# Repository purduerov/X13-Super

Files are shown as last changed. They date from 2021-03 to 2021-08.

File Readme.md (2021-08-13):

# X13-Super-Module

This is an advanced way to manage all the board repos for IEEE ROV. 
Each board's repo is treated as a submodule. 
Git submodules do not track the files inside a submodule, they only point to a commit in the submodule.

### Updating to changes

To get the version pointed at by the super module (this repo), run:  
`git submodule update --init --recursive`  
This can be accessed easier via:  
`git config --global alias.sup 'submodule update --init --recursive'`  
so that you can then type `git sup`

When you cd into a submodule, you will be in a detached HEAD state. You will want to
`git switch` or `git checkout` a branch. To find the branches, run `git branch` or
`git branch -r` to see remote branches.

To get the latest version of each submodule, run:  
`git submodule foreach --recursive git pull`.  
Note: you must be on a branch in order to do this.
Alternatively, running `git submodule update --remote` will pull the latest
commits from the branch tracked in `.gitmodules`, but will finished in a detached head state.

To set up a new submodule, run:  
`git submodule add link.copied.from.github`  
To add tracking the for a branch such as master, use:  
`git submodule add -b master link.copied.from.github`  

### Other: Merging and merge conflicts
Running `git merge --ff-only` or `git pull --ff--only` will prevent git from automatically trying to merge
diverged histories. If you are in a conflict merge commit and want to exit, run `git merge --quit`.  

To merge two branches that have diverged, you have several options. 
1. `git merge -s recursive -X ours` and `git merge -s recursive -X theirs` will attempt to interleave
changes from both files. When conflicts arise, it will prefer local/current (ours) changes in 
`-X ours` and the remote/merging branch (theirs) changes in `-X theirs`.
2. `git merge -s ours` this will "merge" the other branch, but discard all of it's changes.
3. If you have diverged histories and want to delete yours, you can "undo" or "delete" several commits,
then fast-forward merge. It is recommended to first make a "backup" branch (rather than messing with reflog), 
by running `git branch local-backup` (local-backup can be any name). Then run `git reset --hard HEAD~N` where
`N` is the number of commits to undo. The run `git merge branch-name` or `git pull` to fastforward merge the
other branch.

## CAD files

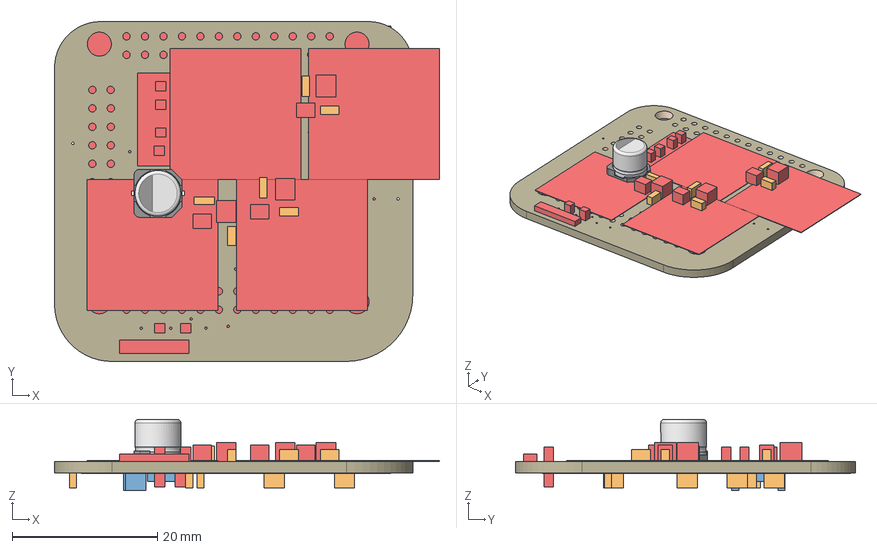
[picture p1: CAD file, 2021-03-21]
NeoCoreShield2.step
52.9 x 46.7 x 9.83 mm
Board
BINDER_M12_PAR_8_DIP x 4
ETH-TRANS
10k x 11
1.0nF
0.1uF x 2
JUMPER-SMT_2_NO_SILK x 8
RED x 6
2.5A/30V/105mΩ x 3
NANO_PI_NEO_CORE
1X04
310mA/60V/1.6Ω x 3
WSIZE CODE D-001
WSIZE CODE D-002
WSIZE CODE D-003 x 2

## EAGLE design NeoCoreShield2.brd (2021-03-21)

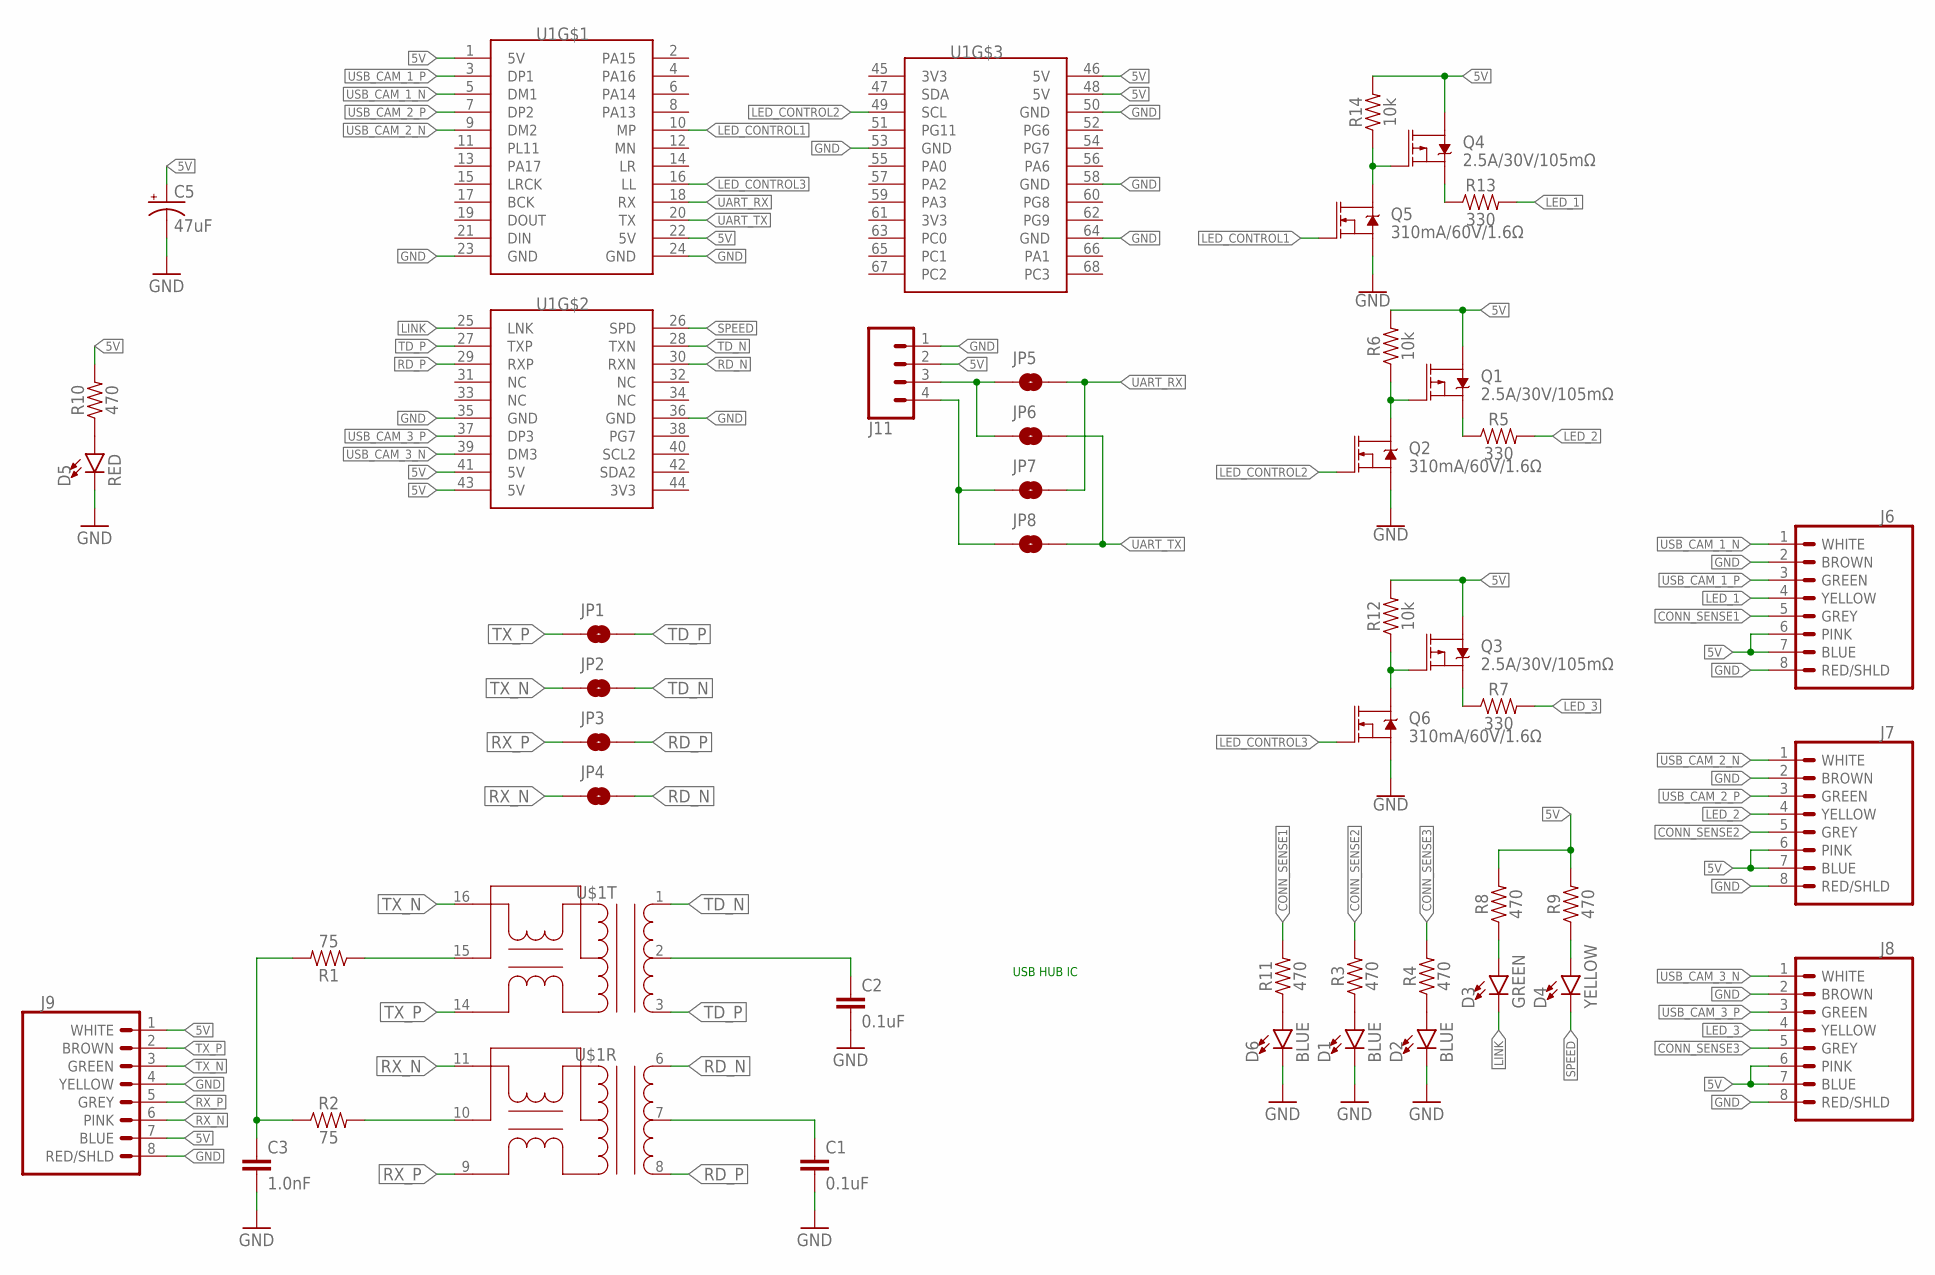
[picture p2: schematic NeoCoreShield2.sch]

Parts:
C1, C2: 0.1uF; 0603
C3: 1.0nF; 1206
C5: 47uF; PANASONIC_D
D1, D2, D6: BLUE; 0805
D3: GREEN; 0805
D4: YELLOW; 0805
D5: RED; 0805
J6, J7, J8, J9: BINDER_M12_PAR_8_DIP
J11: CONN_04; 1X04
JP1, JP2, JP3, JP4, JP5, JP6, JP7, JP8: JUMPER-SMT_2_NO_SILK; SMT-JUMPER_2_NO_SILK
Q1, Q3, Q4: 2.5A/30V/105mΩ; SOT23-3
Q2, Q5, Q6: 310mA/60V/1.6Ω; SOT323
R1, R2: 75; 0603
R3, R4, R8, R9, R10, R11: 470; 0603
R5, R7, R13: 330; 0805
R6, R12, R14: 10k; 0603
U1: NANO_PI_NEO_CORE
U$1: ETH-TRANS; SOIC-16-WIDE

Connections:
5V: C5.+, J6.6 (PINK), J6.7 (BLUE), J7.6 (PINK), J7.7 (BLUE), J8.6 (PINK), J8.7 (BLUE), J9.1 (WHITE), J9.7 (BLUE), J11.2, Q1.3 (D), Q3.3 (D), Q4.3 (D), R6.2, R8.2, R9.2, R10.2, R12.2, R14.2, U1.1 (5V), U1.22 (5V), U1.41 (5V), U1.43 (5V), U1.46 (5V), U1.48 (5V)
CONN_SENSE1: J6.5 (GREY), R11.2
CONN_SENSE2: J7.5 (GREY), R3.2
CONN_SENSE3: J8.5 (GREY), R4.2
ETH_TD0_GND: C1.1, U$1.7 (CT)
ETH_TD1_GND: C2.1, U$1.2 (CT)
ETH_TERM_MID: C3.1, R1.2, R2.1
GND: C1.2, C2.2, C3.2, C5.-, D1.C, D2.C, D5.C, D6.C, J6.2 (BROWN), J6.8 (RED/SHLD), J7.2 (BROWN), J7.8 (RED/SHLD), J8.2 (BROWN), J8.8 (RED/SHLD), J9.4 (YELLOW), J9.8 (RED/SHLD), J11.1, Q2.2 (S), Q5.2 (S), Q6.2 (S), U1.23 (GND), U1.24 (GND), U1.35 (GND), U1.36 (GND), U1.50 (GND), U1.53 (GND), U1.58 (GND), U1.64 (GND)
LED_1: J6.4 (YELLOW), R13.2
LED_2: J7.4 (YELLOW), R5.2
LED_3: J8.4 (YELLOW), R7.2
LED_CONTROL1: Q5.1 (G), U1.10 (MP)
LED_CONTROL2: Q2.1 (G), U1.49 (SCL)
LED_CONTROL3: Q6.1 (G), U1.16 (LL)
LINK: D3.C, U1.25 (LNK)
LINK_MID: D3.A, R8.1
unnamed: D1.A, R3.1
unnamed: D2.A, R4.1
unnamed: R2.2, U$1.10 (XCT)
unnamed: D6.A, R11.1
unnamed: Q3.2 (S), R7.1
unnamed: Q3.1 (G), Q6.3 (D), R12.1
unnamed: D5.A, R10.1
unnamed: Q1.2 (S), R5.1
unnamed: Q1.1 (G), Q2.3 (D), R6.1
unnamed: Q4.2 (S), R13.1
unnamed: R1.1, U$1.15 (XCT)
unnamed: Q4.1 (G), Q5.3 (D), R14.1
RD_N: JP4.2, U1.30 (RXN), U$1.6 (D+)
RD_P: JP3.2, U1.29 (RXP), U$1.8 (D-)
RX_N: J9.6 (PINK), JP4.1, U$1.11 (X+)
RX_P: J9.5 (GREY), JP3.1, U$1.9 (X-)
SPEED: D4.C, U1.26 (SPD)
SPEED_MID: D4.A, R9.1
TD_N: JP2.2, U1.28 (TXN), U$1.1 (D+)
TD_P: JP1.2, U1.27 (TXP), U$1.3 (D-)
TX_N: J9.3 (GREEN), JP2.1, U$1.16 (X+)
TX_P: J9.2 (BROWN), JP1.1, U$1.14 (X-)
UART_RX: JP5.2, JP7.2, U1.18 (RX)
UART_RX_TX: J11.3, JP5.1, JP6.1
UART_TX: JP6.2, JP8.2, U1.20 (TX)
UART_TX_RX: J11.4, JP7.1, JP8.1
USB_CAM_1_N: J6.1 (WHITE), U1.5 (DM1)
USB_CAM_1_P: J6.3 (GREEN), U1.3 (DP1)
USB_CAM_2_N: J7.1 (WHITE), U1.9 (DM2)
USB_CAM_2_P: J7.3 (GREEN), U1.7 (DP2)
USB_CAM_3_N: J8.1 (WHITE), U1.39 (DM3)
USB_CAM_3_P: J8.3 (GREEN), U1.37 (DP3)

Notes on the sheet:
USB HUB IC

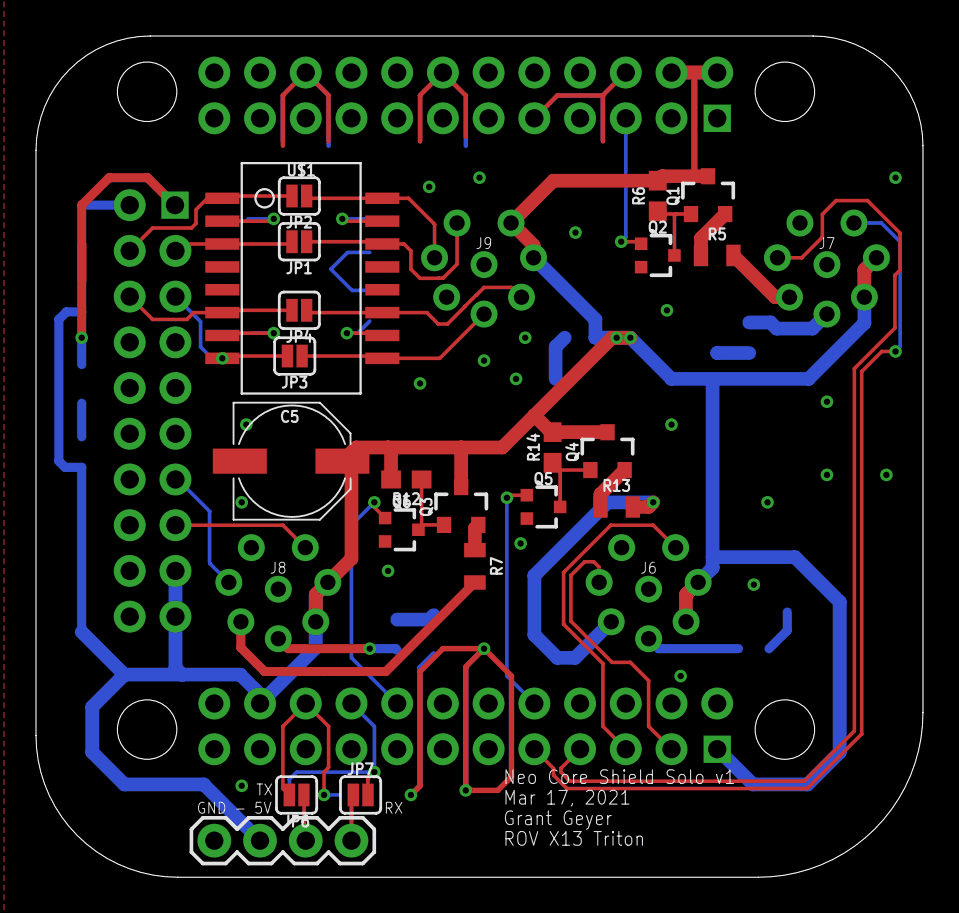
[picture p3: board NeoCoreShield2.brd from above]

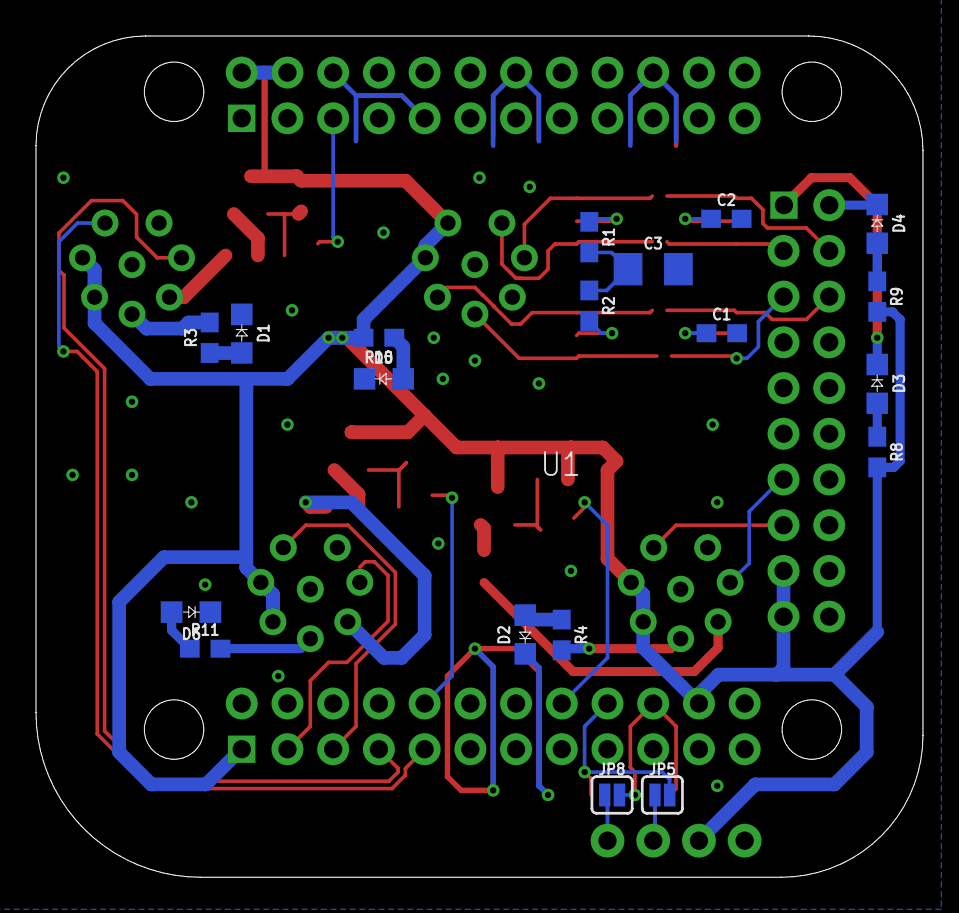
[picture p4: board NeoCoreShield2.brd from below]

Board: 2 copper layers, 49.3 x 46.7 mm, 45 parts (20 on the bottom side), 48 nets.

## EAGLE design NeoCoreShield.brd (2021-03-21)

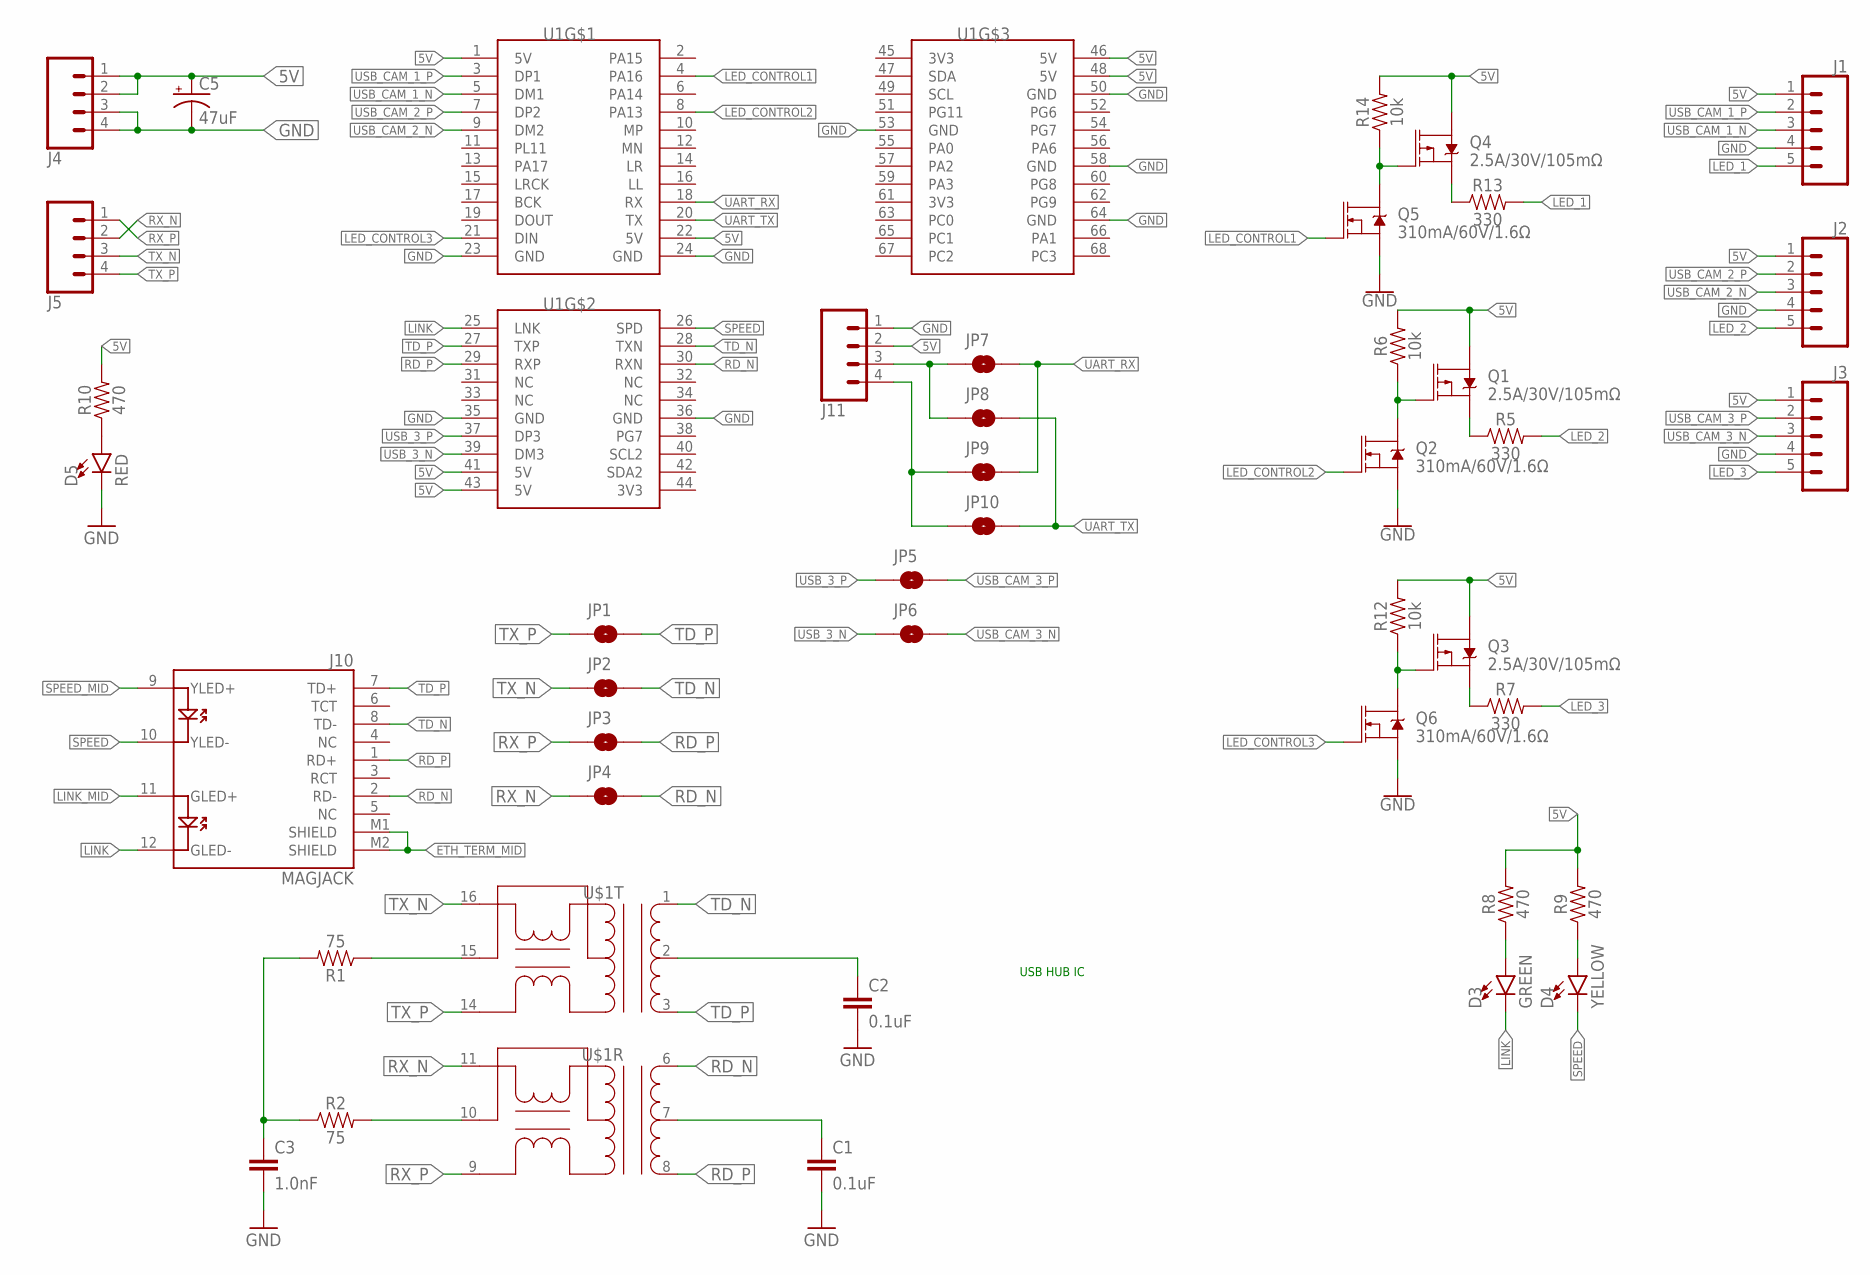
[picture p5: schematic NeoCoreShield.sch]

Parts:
C1, C2: 0.1uF; 0603
C3: 1.0nF; 1206
C5: 47uF; PANASONIC_D
D3: GREEN; 0805
D4: YELLOW; 0805
D5: RED; 0805
J1, J2, J3: PXC-PTSM-05-RA
J4, J5: PXC-PTSM-04-RA-1778641
J10: MAGJACK
J11: CONN_04; 1X04
JP1, JP2, JP3, JP4, JP5, JP6, JP7, JP8, JP9, JP10: JUMPER-SMT_2_NO_SILK; SMT-JUMPER_2_NO_SILK
Q1, Q3, Q4: 2.5A/30V/105mΩ; SOT23-3
Q2, Q5, Q6: 310mA/60V/1.6Ω; SOT323
R1, R2: 75; 0603
R5, R7, R13: 330; 0805
R6, R12, R14: 10k; 0603
R8, R9, R10: 470; 0603
U1: NANO_PI_NEO_CORE
U$1: ETH-TRANS; SOIC-16-WIDE

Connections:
5V: C5.+, J1.1, J2.1, J3.1, J4.1, J4.2, J11.2, Q1.3 (D), Q3.3 (D), Q4.3 (D), R6.2, R8.2, R9.2, R10.2, R12.2, R14.2, U1.1 (5V), U1.22 (5V), U1.41 (5V), U1.43 (5V), U1.46 (5V), U1.48 (5V)
ETH_TD0_GND: C1.1, U$1.7 (CT)
ETH_TD1_GND: C2.1, U$1.2 (CT)
ETH_TERM_MID: C3.1, J10.M1 (SHIELD), J10.M2 (SHIELD), R1.2, R2.1
GND: C1.2, C2.2, C3.2, C5.-, D5.C, J1.4, J2.4, J3.4, J4.3, J4.4, J11.1, Q2.2 (S), Q5.2 (S), Q6.2 (S), U1.23 (GND), U1.24 (GND), U1.35 (GND), U1.36 (GND), U1.50 (GND), U1.53 (GND), U1.58 (GND), U1.64 (GND)
LED_1: J1.5, R13.2
LED_2: J2.5, R5.2
LED_3: J3.5, R7.2
LED_CONTROL1: Q5.1 (G), U1.4 (PA16)
LED_CONTROL2: Q2.1 (G), U1.8 (PA13)
LED_CONTROL3: Q6.1 (G), U1.21 (DIN)
LINK: D3.C, J10.12 (GLED-), U1.25 (LNK)
LINK_MID: D3.A, J10.11 (GLED+), R8.1
unnamed: R2.2, U$1.10 (XCT)
unnamed: Q3.2 (S), R7.1
unnamed: Q3.1 (G), Q6.3 (D), R12.1
unnamed: D5.A, R10.1
unnamed: Q1.2 (S), R5.1
unnamed: Q1.1 (G), Q2.3 (D), R6.1
unnamed: Q4.2 (S), R13.1
unnamed: R1.1, U$1.15 (XCT)
unnamed: Q4.1 (G), Q5.3 (D), R14.1
RD_N: J10.2 (RD-), JP4.2, U1.30 (RXN), U$1.6 (D+)
RD_P: J10.1 (RD+), JP3.2, U1.29 (RXP), U$1.8 (D-)
RX_N: J5.2, JP4.1, U$1.11 (X+)
RX_P: J5.1, JP3.1, U$1.9 (X-)
SPEED: D4.C, J10.10 (YLED-), U1.26 (SPD)
SPEED_MID: D4.A, J10.9 (YLED+), R9.1
TD_N: J10.8 (TD-), JP2.2, U1.28 (TXN), U$1.1 (D+)
TD_P: J10.7 (TD+), JP1.2, U1.27 (TXP), U$1.3 (D-)
TX_N: J5.3, JP2.1, U$1.16 (X+)
TX_P: J5.4, JP1.1, U$1.14 (X-)
UART_RX: JP7.2, JP9.2, U1.18 (RX)
UART_RX_TX: J11.3, JP7.1, JP8.1
UART_TX: JP8.2, JP10.2, U1.20 (TX)
UART_TX_RX: J11.4, JP9.1, JP10.1
USB_3_N: JP6.1, U1.39 (DM3)
USB_3_P: JP5.1, U1.37 (DP3)
USB_CAM_1_N: J1.3, U1.5 (DM1)
USB_CAM_1_P: J1.2, U1.3 (DP1)
USB_CAM_2_N: J2.3, U1.9 (DM2)
USB_CAM_2_P: J2.2, U1.7 (DP2)
USB_CAM_3_N: J3.3, JP6.2
USB_CAM_3_P: J3.2, JP5.2

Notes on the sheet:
USB HUB IC

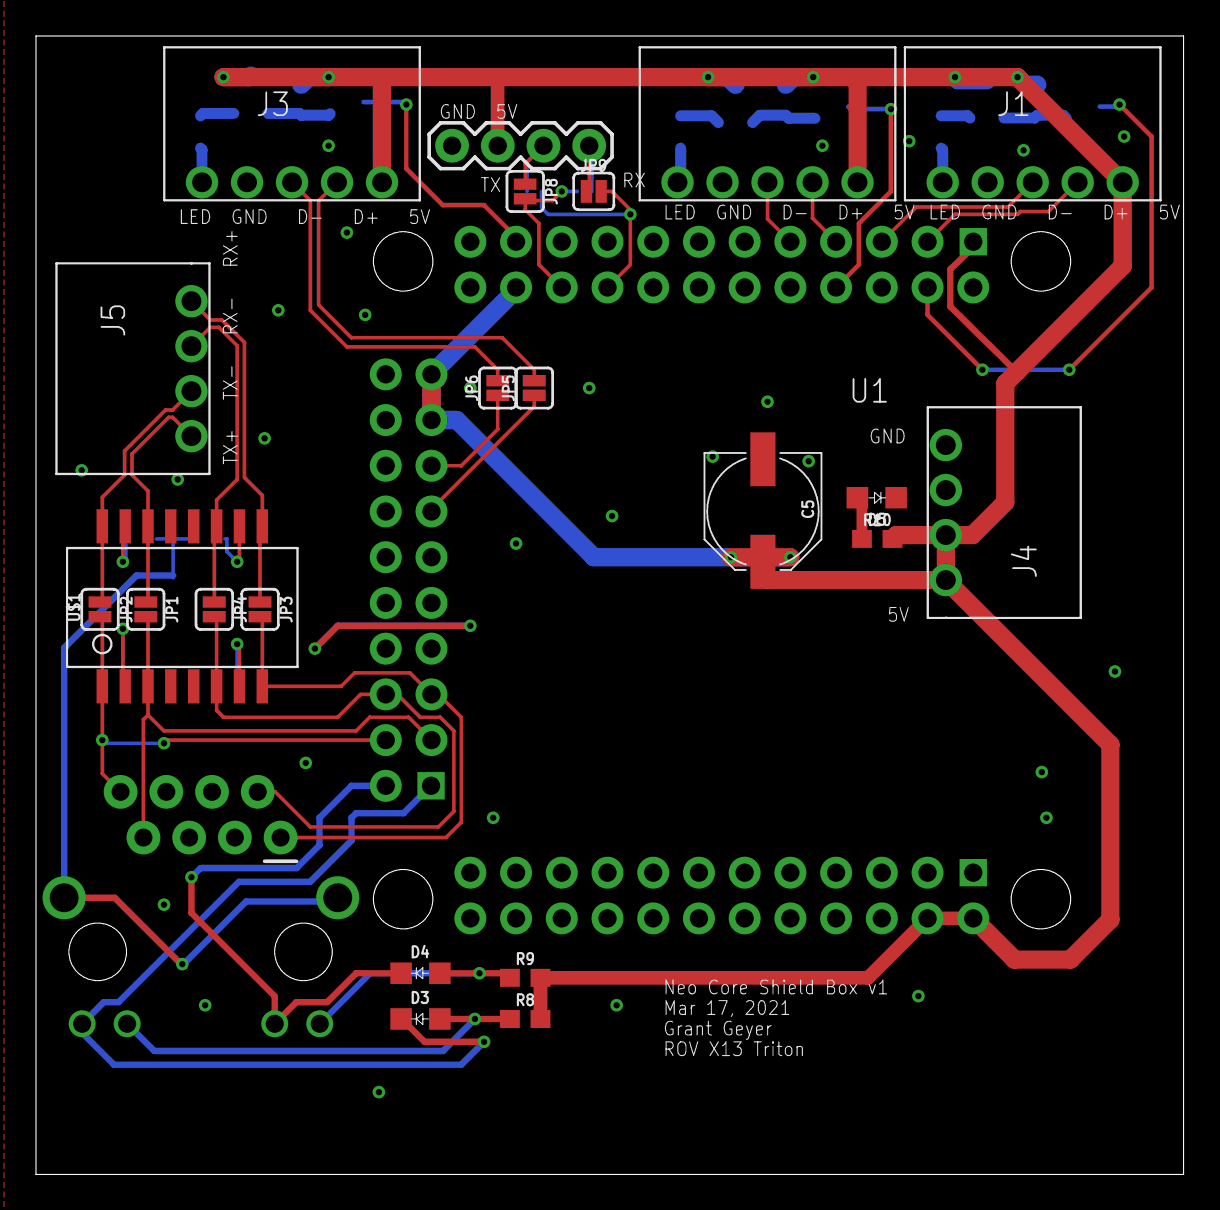
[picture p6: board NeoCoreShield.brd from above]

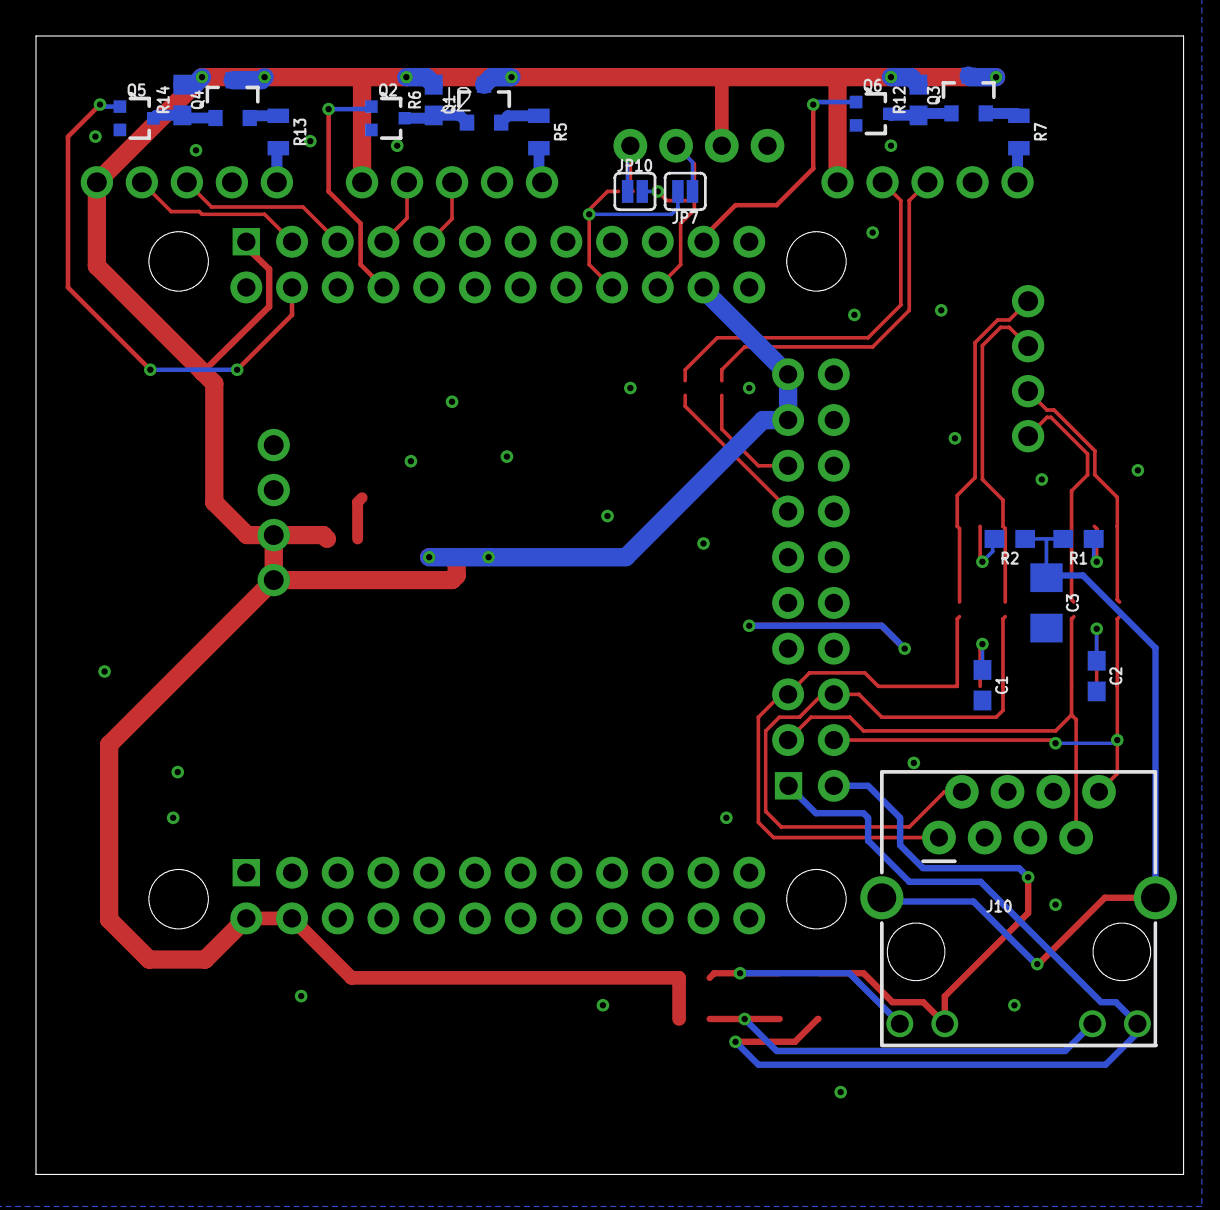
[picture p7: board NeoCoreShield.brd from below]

Board: 2 copper layers, 63.8 x 63.2 mm, 43 parts (20 on the bottom side), 44 nets.

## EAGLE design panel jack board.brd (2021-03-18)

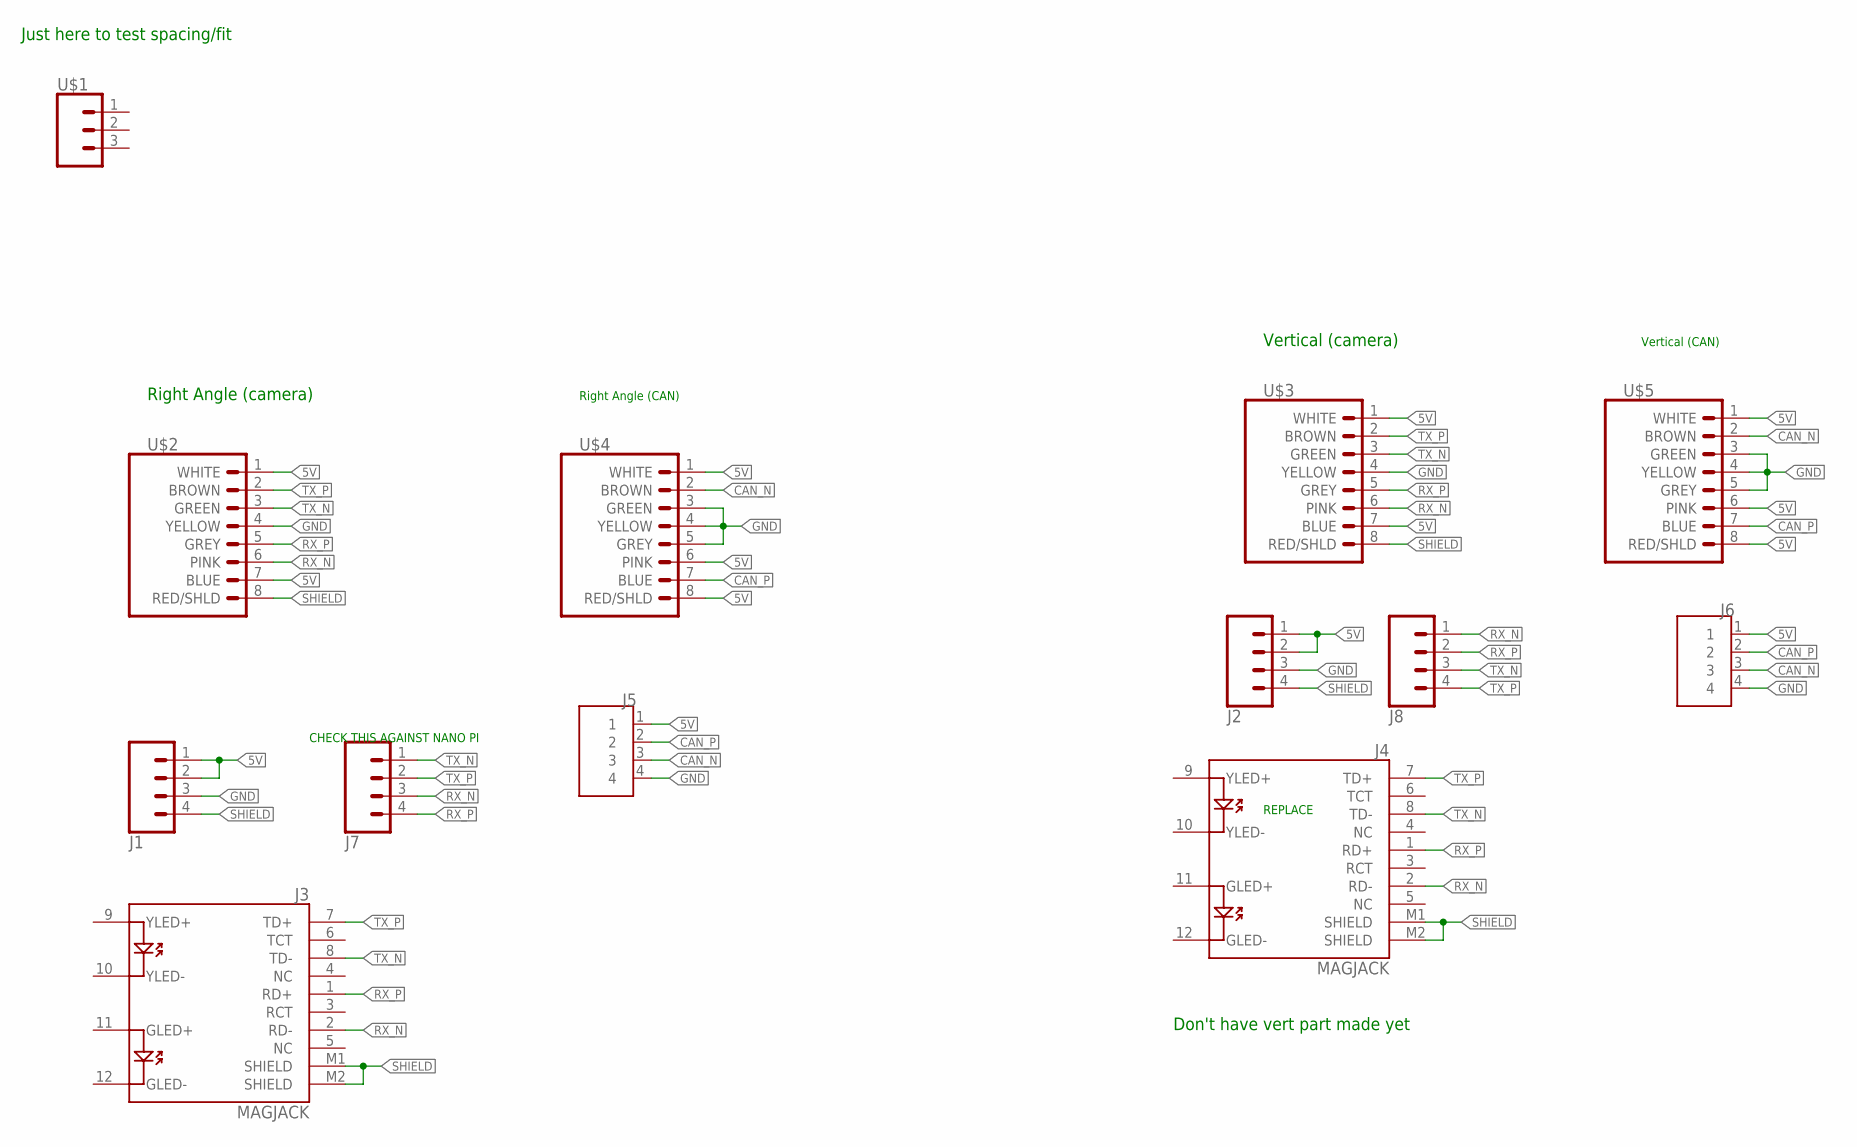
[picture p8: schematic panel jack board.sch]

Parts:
J1, J2, J8: PXC-PTSM-04-V-1778573
J3, J4: MAGJACK
J5, J6: 284512-4; TE_284512-4
J7: PXC-PTSM-04-RA-1778641
U$1: BULGIN_BUC4000_3
U$2, U$4: BINDER_M12_RA_8
U$3, U$5: BINDER_M12_PAR_8_DIP

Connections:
5V: J1.1, J1.2, J2.1, J2.2, J5.1, J6.1, U$2.1 (WHITE), U$2.7 (BLUE), U$3.1 (WHITE), U$3.7 (BLUE), U$4.1 (WHITE), U$4.6 (PINK), U$4.8 (RED/SHLD), U$5.1 (WHITE), U$5.6 (PINK), U$5.8 (RED/SHLD)
CAN_N: J5.3, J6.3, U$4.2 (BROWN), U$5.2 (BROWN)
CAN_P: J5.2, J6.2, U$4.7 (BLUE), U$5.7 (BLUE)
GND: J1.3, J2.3, J5.4, J6.4, U$2.4 (YELLOW), U$3.4 (YELLOW), U$4.3 (GREEN), U$4.4 (YELLOW), U$4.5 (GREY), U$5.3 (GREEN), U$5.4 (YELLOW), U$5.5 (GREY)
RX_N: J3.2 (RD-), J4.2 (RD-), J7.3, J8.1, U$2.6 (PINK), U$3.6 (PINK)
RX_P: J3.1 (RD+), J4.1 (RD+), J7.4, J8.2, U$2.5 (GREY), U$3.5 (GREY)
SHIELD: J1.4, J2.4, J3.M1 (SHIELD), J3.M2 (SHIELD), J4.M1 (SHIELD), J4.M2 (SHIELD), U$2.8 (RED/SHLD), U$3.8 (RED/SHLD)
TX_N: J3.8 (TD-), J4.8 (TD-), J7.1, J8.3, U$2.3 (GREEN), U$3.3 (GREEN)
TX_P: J3.7 (TD+), J4.7 (TD+), J7.2, J8.4, U$2.2 (BROWN), U$3.2 (BROWN)

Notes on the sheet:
Just here to test spacing/fit
Right Angle (camera)
Vertical (camera)
Don't have vert part made yet
Right Angle (CAN)
CHECK THIS AGAINST NANO PI
Vertical (CAN)
REPLACE

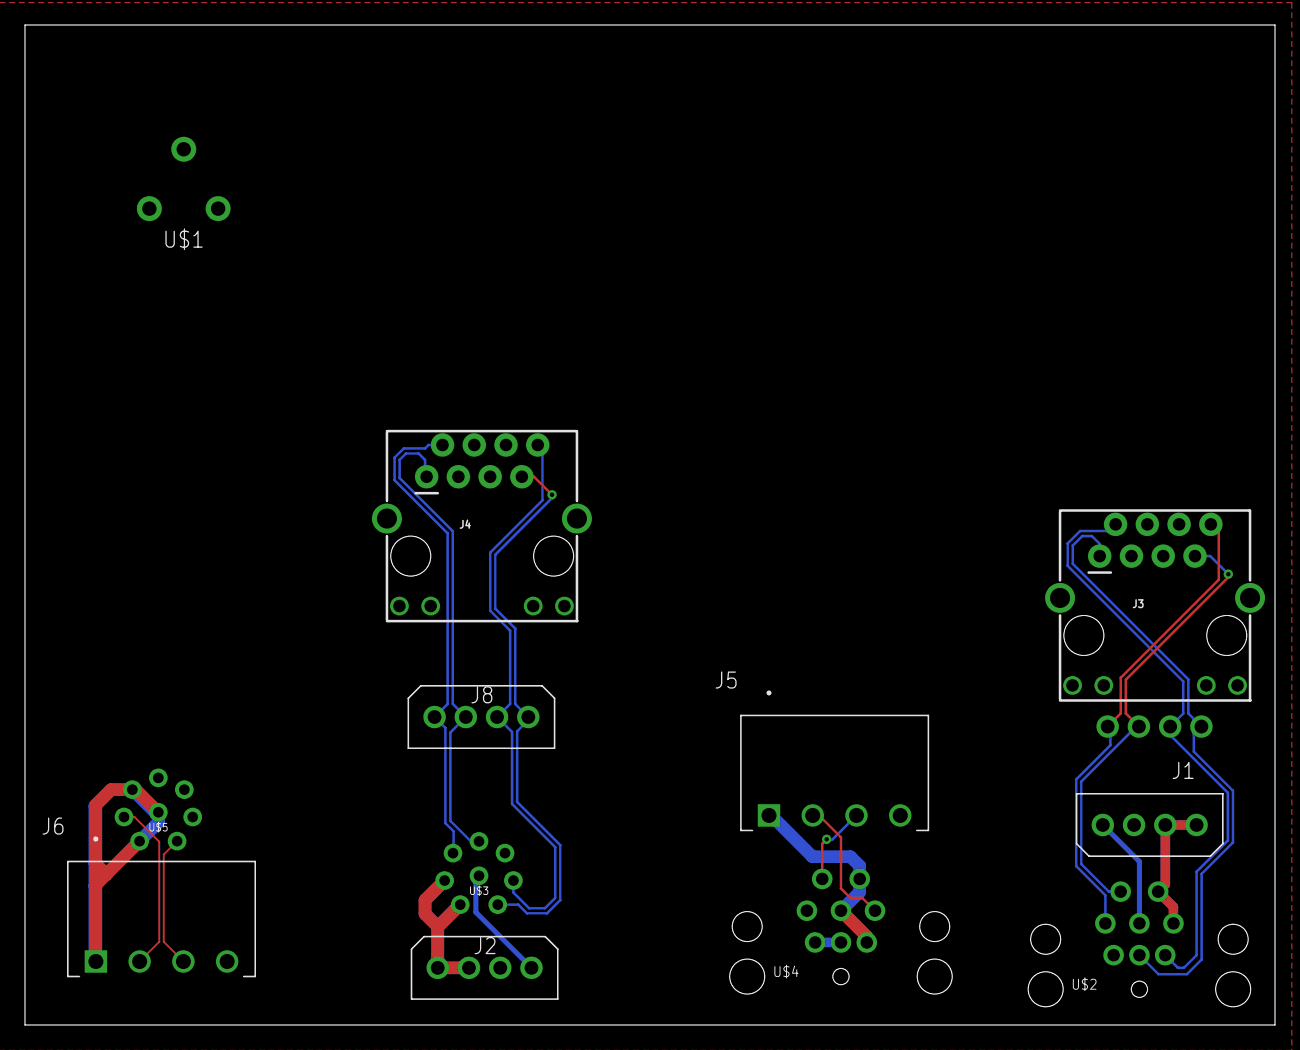
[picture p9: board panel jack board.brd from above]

Board: 2 copper layers, 100.0 x 80.0 mm, 13 parts (1 on the bottom side), 9 nets.

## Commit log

2020-11-12 Add Solenoid and custom esc as modules
2021-01-12 First round of PCB orders
2021-03-17 Neo Core Shield and Panel Jack Test Board and Updates a long time coming
    [NeoCoreShield.brd, NeoCoreShield.sch, NeoCoreShield2.brd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]
2021-03-18 Add panel jack PCB term test board
    [panel jack board.brd, panel jack board.sch]
2021-03-18 Routed Neo Core Shields
    [NeoCoreShield.brd, NeoCoreShield.sch, NeoCoreShield2.brd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]
2021-03-21 Neo Core Nano Pi Shield order
    [NeoCoreShield.brd, NeoCoreShield2.brd, NeoCoreShield2.step]

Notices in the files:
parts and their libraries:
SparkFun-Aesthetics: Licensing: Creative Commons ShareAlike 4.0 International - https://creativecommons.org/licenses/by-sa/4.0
